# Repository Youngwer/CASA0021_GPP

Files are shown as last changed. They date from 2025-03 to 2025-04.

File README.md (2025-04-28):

LitMate Title

<a href="https://www.youtube.com/watch?v=BeWCd5zH7cs">
  LitMate Demo Video
</a>

🎥 Click the video above to watch [Your New Reading Partner](https://www.youtube.com/watch?v=BeWCd5zH7cs)

# LitMate: Smart Book Light for Shared Reading Experiences

## 📖 What the Project Does

LitMate is a smart book light that combines IoT technology with behavioral development concepts to help users build consistent reading habits. Using the MQTT protocol, LitMate enables remote users to share their reading status in real-time, fostering mutual companionship and accountability.

Product demo of LitMate

**Key Features:**
- Physical book light with open/close mechanism showing reading status
- Visual Pomodoro timer through page angle movement
- LED indicators showing reading progress for yourself and your reading partner
- Touch sensor for interaction and color changes
- Companion mobile app for tracking reading statistics and connecting with other readers
- WiFi connectivity with easy setup through Access Point mode
- MQTT protocol for real-time status synchronization between paired devices

<br clear="left"/>

## 🌟 Why the Project is Useful

LitMate addresses the challenge many readers face: difficulty in maintaining consistent reading habits. According to a 2019 Harris Poll, 81% of U.S. adults report not reading as much as they wish due to limited time. Research on the "false hope syndrome" explains this pattern of repeated failure and renewed intention (Polivy & Herman, 2002).

LitMate transforms reading from a solitary activity into a shared experience by:
1. **Creating accountability** through paired devices that show when your partner is reading
2. **Visualizing progress** with physical and light indicators
3. **Building routine** through Pomodoro timing techniques
4. **Fostering community** via the companion app's social features
5. **Reducing distractions** by making reading time visible and meaningful

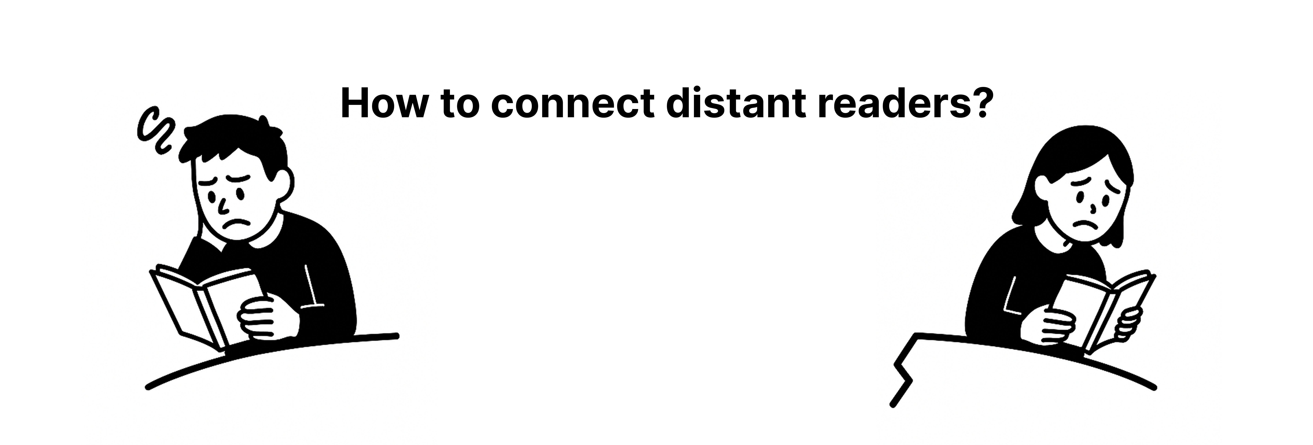
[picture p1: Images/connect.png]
How to connect distant readers

<p style="text-align: center;"><em>How LitMate connects distant readers</em></p>

## 🚀 How Users Can Get Started with the Project

### Materials Required

| Component | Quantity | Estimated Cost (GBP) | Notes |
|---|---|---|---|
| ESP32 Development Board | 1 | £7.2 | Main controller |
| SW420 Vibration Sensor | 1 | £0.8 | For touch detection |
| Servo Motor | 2 | £4.4 | Controls book opening/closing |
| WS2812B LED Strip | 4 segments (8 LEDs each) | £11.0 | For status display |
| Push Button | 1 | £0.4 | Stainless steel button |
| 4xAA Battery Holder | 1 | £0.8 | 6V power supply |
| Acrylic Sheets | - | £8.3 | Textured acrylic recommended |
| Other Components | - | £2.8 | Wires, resistors, etc. |

### Step 1: Hardware Assembly

1. **3D Modeling & Fabrication:**
   - Use the provided [Rhino files](./3D_Models/) for the enclosure design
   - Laser cut the components from acrylic sheets using the [DWG files](./Laser_Cutting/)
   - Follow the [assembly guide](./Documentation/assembly_guide.md) for detailed instructions

2. **Paper Folding:**
   - Use the [origami template](./Documentation/origami_template.pdf) to create the book page structure
   - Attach pages to the servo motors following the diagram in the assembly guide

3. **Circuit Connection:**
   - Wire the components according to the [circuit diagram](./PCB%20Design/Circuit%20diagram.png)
   - For a more permanent solution, the [PCB design](./PCB%20Design/PCB.png) can be manufactured

### Step 2: Software Setup

1. **Prerequisites:**
   - Install [Arduino IDE](https://www.arduino.cc/en/software)
   - Install ESP32 board package via Boards Manager
   - Install required libraries:
     - WiFiManager
     - PubSubClient (MQTT)
     - FastLED
     - ESP32Servo

2. **Loading the Code:**
   - Clone this repository: `git clone https://github.com/yourusername/litmate.git`
   - Open the [Arduino project](./Arduino/) in Arduino IDE
   - Update the `arduino_secrets.h` file with your WiFi and MQTT broker details
   - Upload the code to your ESP32

3. **First Boot & WiFi Setup:**
   - Power on the device
   - Connect to the "ESP32-Config" WiFi network from your phone/computer
   - Navigate to http://192.168.4.1 in a browser
   - Enter your home WiFi credentials
   - The device will restart and connect to your network

### Step 3: Mobile App Setup

1. **Installing the App:**
   - Download the APK from the [Releases](https://github.com/yourusername/litmate/releases) page
   - Install on your Android device (currently Android-only)

2. **Setting Up Your Profile:**
   - Create an account
   - Set reading goals
   - Add books to your library
   - Connect with friends or join reading groups

### Step 4: Pairing Devices

1. Configure both LitMate devices to use the same MQTT broker
2. Assign each device a unique ID in the code (DeviceA and DeviceB)
3. Both devices will automatically synchronize when connected to the network

## 🤝 Where Users Can Get Help

- **Documentation:** Complete documentation is available in the [Documentation](./Documentation/) folder
- **Issues:** Submit problems or feature requests through [GitHub Issues](https://github.com/yourusername/litmate/issues)
- **Discussions:** Join our [Discord community](https://discord.gg/litmate) to connect with other makers
- **Contact:** Reach the development team at litmate@example.com

## 👥 Who Maintains and Contributes to the Project

LitMate was developed by the CEuniverse Team as part of the CASA0016 Making & Prototyping course at UCL:

<div style="text-align: center;">
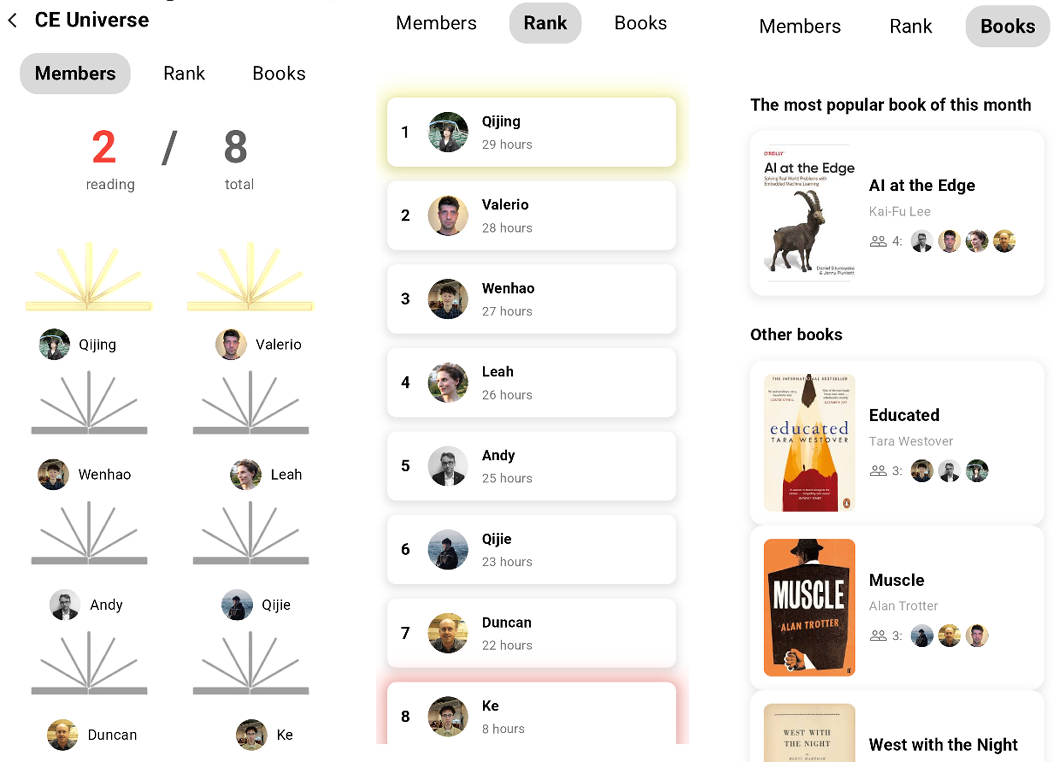
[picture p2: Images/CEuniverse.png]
CEuniverse Team
    
</div>

Team members:
- [Member 1] - Hardware Design & Fabrication
- [Member 2] - Software Development
- [Member 3] - Mobile App Development
- [Member 4] - Product Design
- [Member 5] - Documentation & Testing

## 🔧 Technical Details

### System Architecture

<div style="text-align: center;">
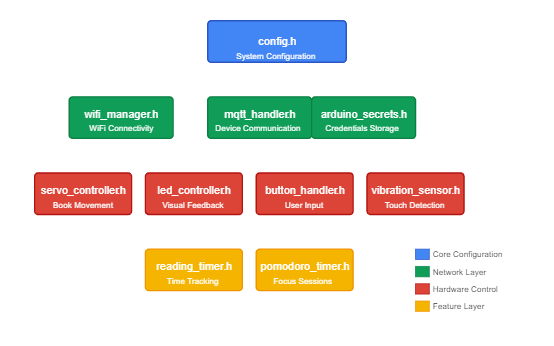
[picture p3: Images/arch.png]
System Architecture
    
</div>

When significant state changes occur (book opening/closing, touch interaction, light color change), the device immediately publishes updates to the appropriate topics. The MQTT client maintains persistent connections with automatic reconnection mechanisms to ensure connected devices receive the latest state information.

Therefore, this lightweight communication framework enables the paired LitMate devices to maintain synchronized state and respond to each other's actions in real-time within seconds.

### 4.3 Core Reading Functionality
The core of LitMate's functionality revolves around its ability to physically interact with books, track reading sessions, and provide visual feedback through an integrated system of hardware control and state management.

#### 4.3.1 Pomodoro Timer 
The LitMate device incorporates a sophisticated Pomodoro timer that combines time tracking with physical visualization through servo motor positioning.

The Pomodoro functions are tightly integrated with the book state management system: When book is open, it start working, set an hour Pomodoro timer; When the full one-hour session completes, it triggers the book closure mechanism.

##### Servo Angle as Visual Progress Indicator
Another feature of LitMate's Pomodoro is the use of servo angle position as a physical progress indicator. As reading time advances, the servo motors adjust their position in 15-degree increments:

```cpp
if (currentStage != lastServoStage) {
        // Calculate new servo position: starting from 180 degrees, decreasing by 15 degrees per stage
        int targetPosition = 180 - (currentStage * DEGREES_PER_STAGE);
        
        // Smoothly move to the new position
        moveServosSmooth(180 - (lastServoStage * DEGREES_PER_STAGE), 
                          targetPosition, 
                          (lastServoStage < currentStage) ? 5 : -5, 
                          50);
        
        lastServoStage = currentStage;
    }

```

#### 4.3.2 Button Interaction Logic (Short Press vs. Long Press)
The system uses a single button interface with differentiated press durations to control multiple functions. The button handler utilise debouncing and timing mechanisms to distinguish between short and long presses:
- **Short Press**: Toggles the progress indicator LEDs on/off.
- **Long Press (for more than 3 seconds)**: Toggles the book's open/closed state.

```cpp
// Function to check button status
void checkButton() {
    // Read button state (LOW means pressed)
    int buttonState = digitalRead(BUTTON_PIN);
    
    // Button pressed
    if (buttonState == LOW && !buttonPressed) {
        buttonPressed = true;
        buttonPressTime = millis();
        longPressTriggered = false;
    } 
    
    // Button held down, check if long press duration is reached
    else if (buttonState == LOW && buttonPressed) {
        unsigned long pressDuration = millis() - buttonPressTime;
        
        // Long press duration reached and long press action not yet triggered
        if (pressDuration >= LONG_PRESS_TIME && !longPressTriggered) {
            toggleBook();         // Toggle the book's open/close status
            longPressTriggered = true;
            Serial.println("Long press detected, toggling book status");
        }
    }
    // Button released
    else if (buttonState == HIGH && buttonPressed) {
        unsigned long pressDuration = millis() - buttonPressTime;
        buttonPressed = false;
        
        // Short press - control LED lights
        if (pressDuration < LONG_PRESS_TIME && !longPressTriggered) {
            toggleLEDs();
            Serial.println("Short press detected, toggling LED status");
        }
        longPressTriggered = false;
    }
}
```

#### 4.3.3 Session-based and Cumulative Time Tracking
The system can distinguish between active reading sessions and cumulative daily reading time. When the book is opened, a new reading session begins. The system uses the millis() function to track time and records the start time and begins tracking the session duration. When the book is closed, the session duration is calculated and added to the cumulative daily reading time. This approach allows the system to maintain accurate time records even through multiple reading sessions throughout the day. The related code is shown below:
```cpp
// Start reading timer
void startReadingTimer() {
    startTime = millis();
    lastUpdateTime = startTime;
    Serial.println("Reading session started!");
    
    // Publish reading status to MQTT
    publishReadingStatus(true, dailyReadingTime);
}
// Stop reading timer
void stopReadingTimer() {
    if (startTime > 0) {
        unsigned long sessionTime = millis() - startTime;
        dailyReadingTime += sessionTime;
        Serial.print("Reading session ended. Session time: ");
        printTime(sessionTime);
        Serial.print("Total daily reading time: ");
        printTime(dailyReadingTime);
        
        // Publish reading status to MQTT
        publishReadingStatus(false, dailyReadingTime);
        
        startTime = 0;
    }
}
```

#### 4.3.4 Daily Reading Reset Mechanism
When a new day begins, the system logs the previous day's total reading time, resets the counter, and publishes the updated state to the MQTT network to ensure paired devices are synchronized.

### 4.4 User Interaction and Data Visualisation

#### 4.4.1 LED Indication System

##### Book Lamp
The main book lamp serves as both a reading light and a status indicator, using color and animation effects to visualise the device's state.

When both books are open, the Book Lamp will display a smooth "breathing" effect that provides ambient lighting, which enhances the reading experience across both users, creating a reading atmosphere.

```cpp
void updateBreathingEffect() {
    unsigned long currentTime = millis();
    if (currentTime - lastBreathTime >= BREATH_INTERVAL) {
        if (increasing) {
            brightness += 5;
            if (brightness >= 255) {
                brightness = 255;
                increasing = false;
            }
        } else {
            brightness -= 5;
            if (brightness <= 0) {
                brightness = 0;
                increasing = true;
            }
        }
	lastBreathTime = currentTime;
}
```
The book lamp color can be changed between pink (default) and yellow through the vibration sensor double-tap detection, which is design for interactive purposes to increase fun through readers:
```cpp
if (tapInterval > minTapInterval && tapInterval < doubleTapWindow) {
    // Toggle light color and publish
    isYellowColor = !isYellowColor;
    publishLightColor(isYellowColor);
    
    // Apply the new color to LEDs
    if (isYellowColor) {
        setLEDColor(255, 255, 0);  // Yellow
    } else {
        setLEDColor(255, 102, 178);  // Pink
    }
}

```
This color change is synchronized between paired devices, creating a shared visual experience between remote users.

#### 4.4.2 Progress Indicator LEDs

The system implements separate LED strips for each user, which can be identified by color, to visualise reading time for both the user's device and the paired device. The number of LED display logic is shown in code below:
```cpp
// Map reading time to LED display (8 LEDs represent progress thresholds)
    int ledsToLight = 0;
    if (totalSeconds < 450) {
        ledsToLight = 1;
    } else if (totalSeconds < 900) {
        ledsToLight = 2;
    } else if (totalSeconds < 1350) {
        ledsToLight = 3;
    } else if (totalSeconds < 1800) {
        ledsToLight = 4;
    } else if (totalSeconds < 2250) {
        ledsToLight = 5;
    } else if (totalSeconds < 2700) {
        ledsToLight = 6;
    } else if (totalSeconds < 3150) {
        ledsToLight = 7;
    } else {
        ledsToLight = 8;
    }
```

Also, these reading progress LEDs can be switched on and off via a short button press to conserve power, which is shown below:
```cpp
    if (!progressLEDsEnabled) {
        // Turn off both progress bar LEDs
        timeStrip.clear();
        timeStrip.show();
        
        deviceBTimeStrip.clear();
        deviceBTimeStrip.show();
    } else {
        // Re-enable progress bar LEDs
        updateTimeLEDs();
        updateDeviceBTimeLEDs();
    }
```

# 5. Application

### 5.1 Overview
The mobile application aims to provide users with a simple reading record and reading sharing experience. It ensures that users can record the current reading time and number of pages, and view past reading statistics through the app to achieve better development of reading habits.

### 5.2 Main Functions
#### 5.2.1 Recording reading time and pages

<div style="text-align: center;">
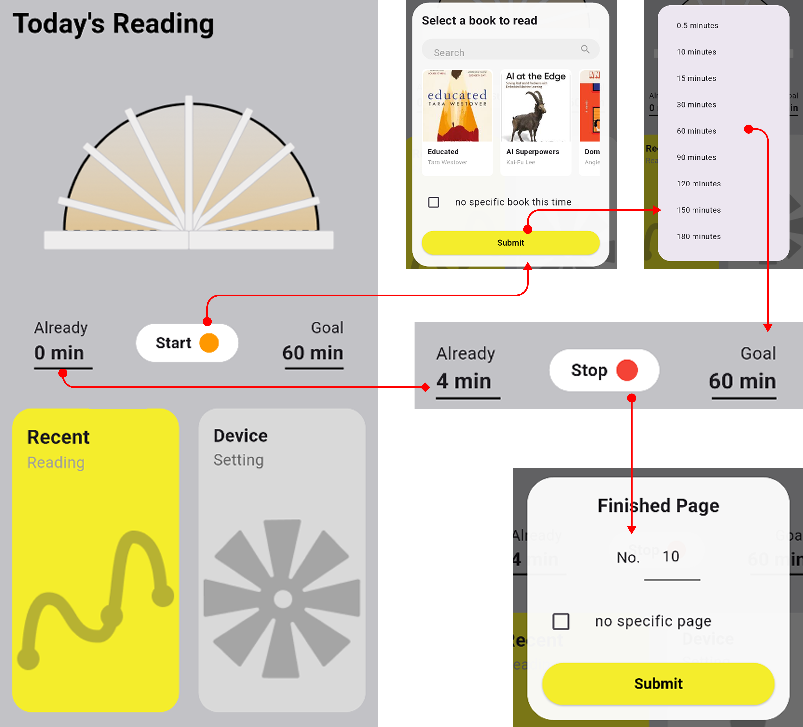
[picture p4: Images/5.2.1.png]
Recording reading time and pages interface
    
    <p><em>Fig 24. Interface for recording reading time and pages</em></p>
</div>

- Click on the 'Goal' button and select the goal for today's reading time in the pop-up window.
- Click on the 'Start' button to select the book you are going to read in the pop-up window (the data of the book in the pop-up window comes from the Library).
- After starting to read, the 'Already' text will show the length of time already read, users can click the 'Stop' button to stop reading records, you can enter the progress of this reading in the pop-up window that appears after clicking.

#### 5.2.2 Viewing Reading Statistics

<div style="text-align: center;">
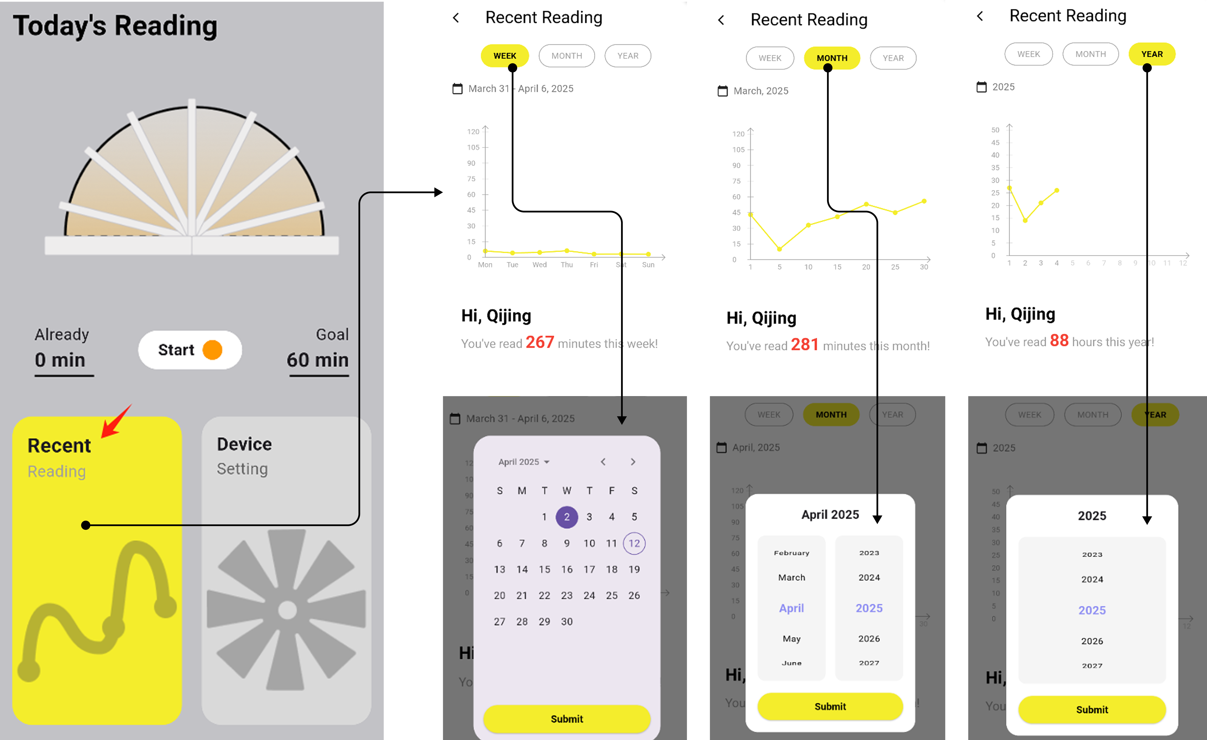
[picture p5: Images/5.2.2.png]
Reading statistics overview
    
    <p><em>Fig 25. Reading statistics overview showing weekly, monthly, and yearly views with time selection</em></p>
</div>

- Click on 'Recent Reading' on the homepage to go to the statistics page. 
- Click on 'WEEK', 'MONTH', 'YEAR' to see reading statistics in different time units.
- Click on the calendar icon to select a time in the pop-up window

#### 5.2.3 Managing Personal Library

<div style="text-align: center;">
    Personal library interface
    <p><em>Fig 26. Personal library interface showing book collection with progress bars</em></p>
</div>

- The book cards on the Library page show each book's cover, title, author, and current reading progress bar.
- Click on the 'Add a new book' card to add a book to the e-library and enter information about the new book in the pop-up window.
- In the search box, you can enter the name of the book or author to search for existing book data.

#### 5.2.4 Managing Personal Library
Click the plus sign on the Group page to create a new group, and enter the group information in the pop-up window.
<div style="text-align: center;">
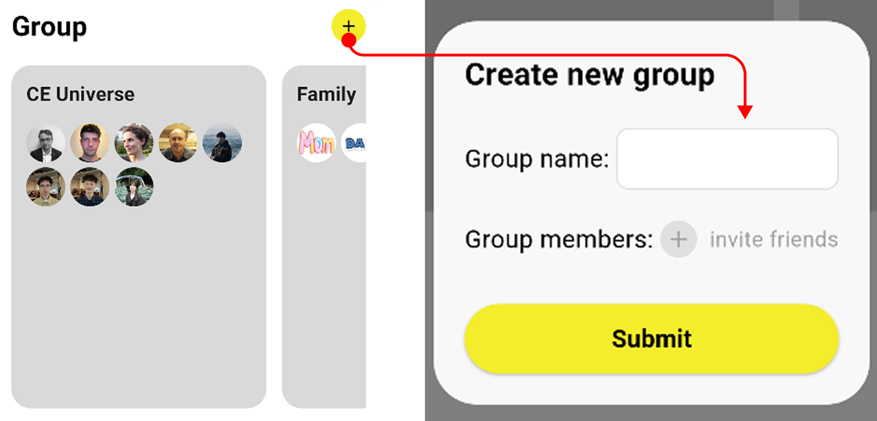
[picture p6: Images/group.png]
Group Photo
    
    <p><em>Fig 27. Group Photo</em></p>
</div>

Click on each Group card to see more information about the group, including the number of members currently reading, the ranking of reading hours for the month, and the books read by group members.
<div style="text-align: center;">
    CEuniverse
    <p><em>Fig 28. CEuniverse Team</em></p>
</div>

### 5.3 Interation
#### 5.3.1 Sketch

<div style="text-align: center;">
    App interface sketch
    <p><em>Fig 29. Initial sketches of the app interface design</em></p>
</div>

#### 5.3.2 Prototype

<div style="text-align: center;">
    App interface prototype
    <p><em>Fig 30. High-fidelity prototype of the app interface</em></p>
</div>

#### 5.3.3 Current Development

<div style="text-align: center;">
    Current app development
    <p><em>Fig 31. Current development status of the app interface</em></p>
</div>

# **6. Limitations & Future development**
### 6.1 More Possibilities in Design

<div style="text-align: center;">
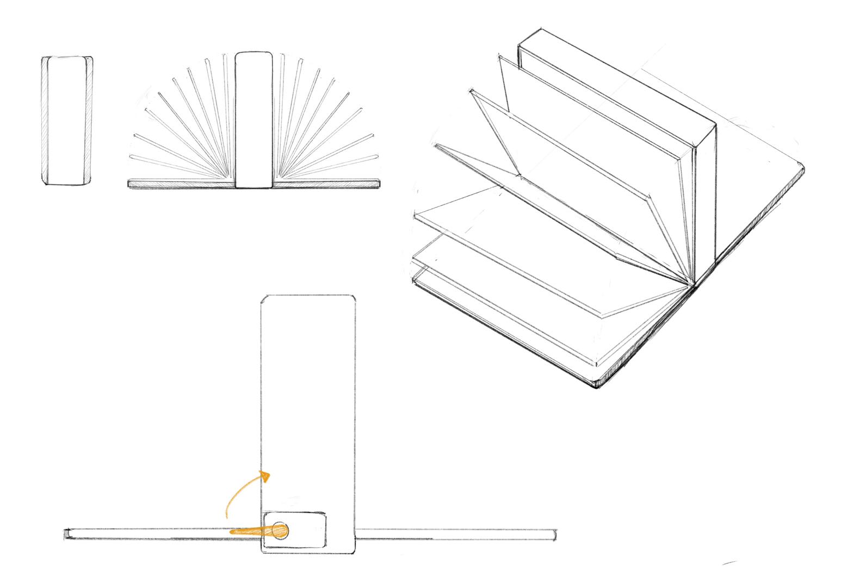
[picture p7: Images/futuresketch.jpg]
Future Design Possibilities
    
    <p><em>Fig 32. Future Design Possibilities</em></p>
</div>
Some of the advice about the product gained during the pitch made the team rethink about product design.

- **Size**: The team tends to reduce the size of the product in the next iteration by upgrading the hardware to make it more write and easy to use. In fact, the current product still has a lot of free space inside.
- **Visualisation**: For visualisation, the team preferred to make another prototype where the pages of the book could be opened from each side to represent the reading progress of both sides for a more intuitive comparison.

### 6.2 How to Improve Hardware of LitMate?
#### 6.2.1 Circuit Assembly and Challenges
The circuit was designed to be straightforward, focusing on ease of connection. However, the symmetrical layout made wiring more complex, leading to issues in organization and debugging. The key challenges faced during assembly were:
- **Complex Wiring Layout**: The symmetrical arrangement of components made routing difficult, increasing the risk of loose connections.
- **Power Supply Limitations**: The initial single power source was insufficient for stable operation, especially when driving multiple LEDs and servos.
- **Vibration Sensor Sensitivity**: The SW420 sensor was difficult to fine-tune, sometimes failing to detect subtle touches or triggering false readings.

To address these issues, some measures were taken :
1) Simplified the routing layout, reducing unnecessary wiring complexity.
2) Implemented a separate power supply, ensuring adequate power distribution.
3) Adjusted the sensitivity threshold of the SW420 sensor to improve its reliability.

#### 6.2.2 PCB Design
For the purpose of simplifying the hardware assembly of the product as well as reducing the size of the product. Designing a dedicated PCB is an ideal ending solution and the team has made the following attempts so far:

<div style="text-align: center;">
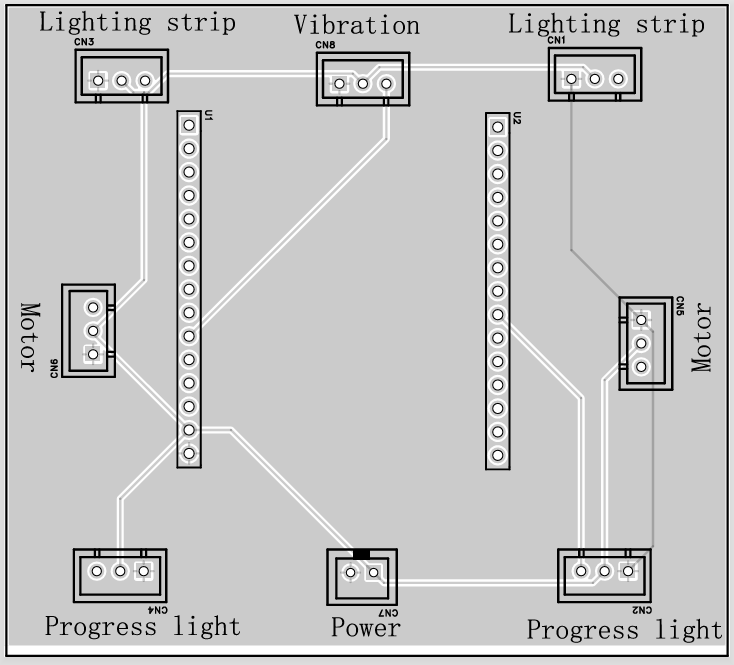
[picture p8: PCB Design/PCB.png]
PCB Design
    
    <p><em>Fig 33. PCB Design</em></p>
</div>

### 6.3 Application

The current APP is limited to Android mobile phones and has not yet been linked to a physical book light, which could be developed in both directions in future developments and iterations: 
1) Develop different versions of the app for Android and IOS phones; 
2) Implement a digital twin between mobile application and physical book light, allowing users to control the book light on/off and synchronise the reading time recorded by the book light in the application.

### 6.4 Marketisation：Inability to finally recognise costs
Below are the current individual equipment costing：

| Component | Quantity | Subtotal (GBP) | Estimated Cost (GBP) | Notes |
|---|---|---|---|---|
| ESP32 Development Board | 1 | £5.5-£8.8 | £7.2 | Main controller |
| SW420 Vibration Sensor | 1 | £0.55-£1.1 | £0.8 | For touch detection |
| Servo Motor | 2 | £3.3-£5.5 | £4.4 | Controls book opening/closing |
| WS2812B LED Strip | 4 segments (8 LEDs each) | £8.8-£13.2 | £11.0 | For status display |
| Push Button | 1 | £0.22-£0.55 | £0.4 | Stainless steel button |
| 4xAA Battery Holder | 1 | £0.55-£1.1 | £0.8 | 6V power supply |
| Acrylic Enclosure | - | £5.5-£11 | £8.3 | Including laser cutting cost |
| Other Components (Wires, Resistors, etc.) | - | £2.2-£3.3 | £2.8 | Basic electronic components |
| **Total** | - | **£26.6-£44.5** | **£35.7** | - |

The ultimate goal of the product is to sell it on kickstater, so the cost and selling price need to be considered, but there are two uncertainties at the moment: the **paper-folding work** needs to seek cooperation from manufacturers for mass production, and the **subsequent development and maintenance costs of the APP**.

# **7. Reference**
1) Polivy, J., & Herman, C. P. (2002). If at First You Don't Succeed: False Hopes of Self-Change. American Psychologist, 57(9), 677–689. https://doi.org/10.1037/0003-066X.57.9.677
2) Harris Poll (2019). Reading Habits Survey, conducted for Scribd. Summary available via Mental Floss by Garin Pirnia: 81% of people don't read as much as they want
3) Wing, R. R., & Jeffery, R. W. (1999). Benefits of recruiting participants with friends and increasing social support for weight loss and maintenance. Journal of Consulting and Clinical Psychology, 67(1), 132–138. https://doi.org/10.1037/0022-006X.67.1.132

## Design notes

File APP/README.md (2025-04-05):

# **workshop7app**

A new Flutter project.

## **Getting Started**

This project is a starting point for a Flutter application.

A few resources to get you started if this is your first Flutter project:

- [Lab: Write your first Flutter app](https://docs.flutter.dev/get-started/codelab)
- [Cookbook: Useful Flutter samples](https://docs.flutter.dev/cookbook)

For help getting started with Flutter development, view the
[online documentation](https://docs.flutter.dev/), which offers tutorials,
samples, guidance on mobile development, and a full API reference.

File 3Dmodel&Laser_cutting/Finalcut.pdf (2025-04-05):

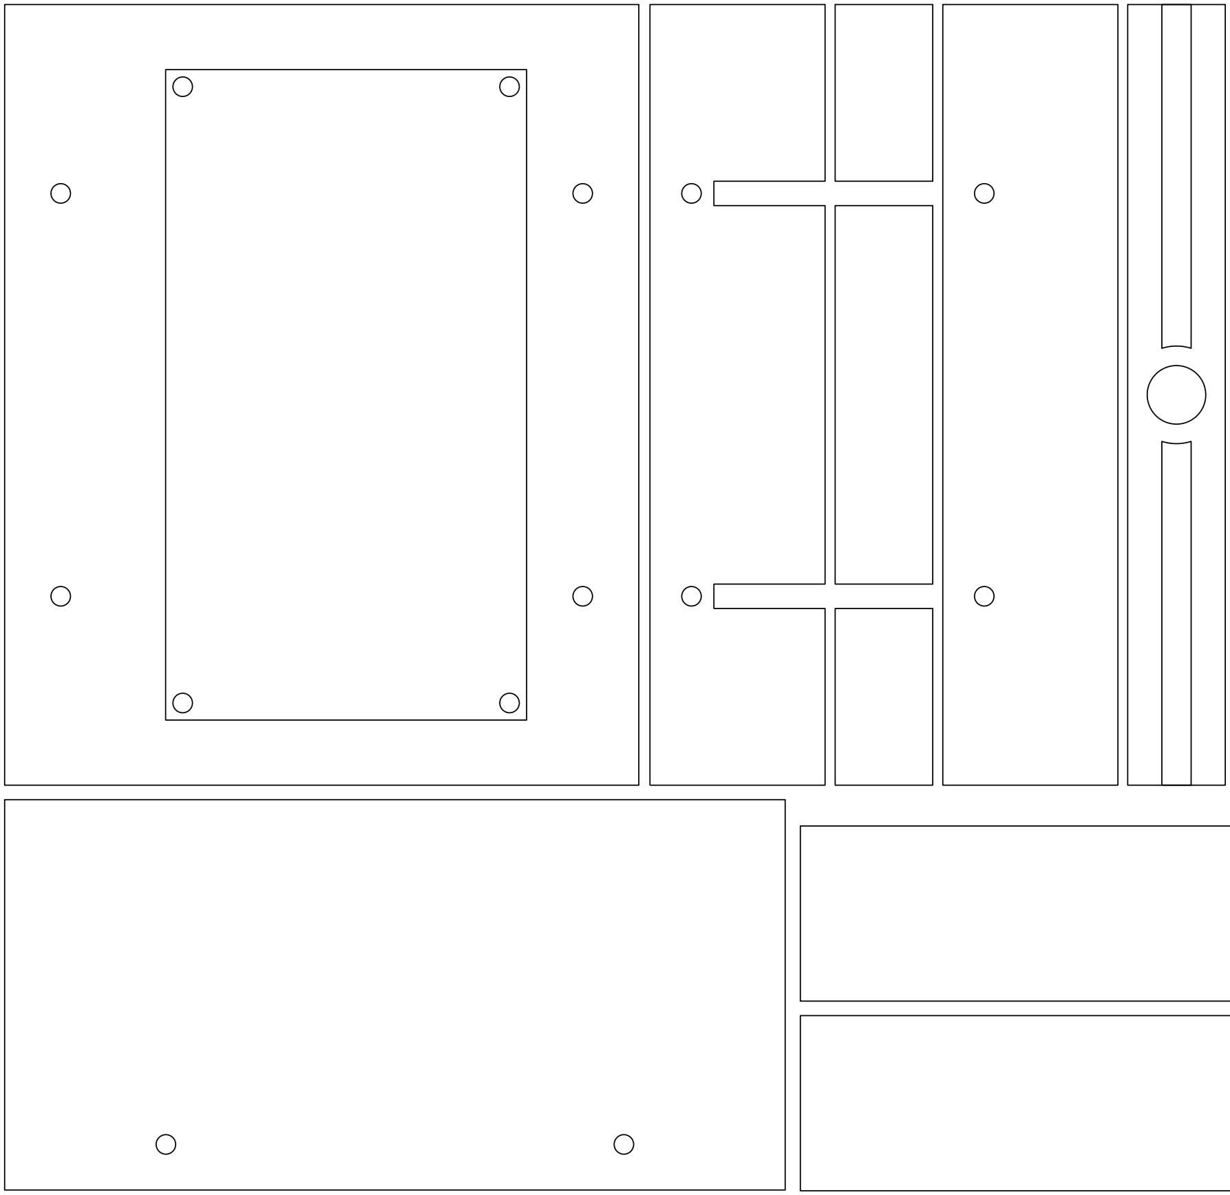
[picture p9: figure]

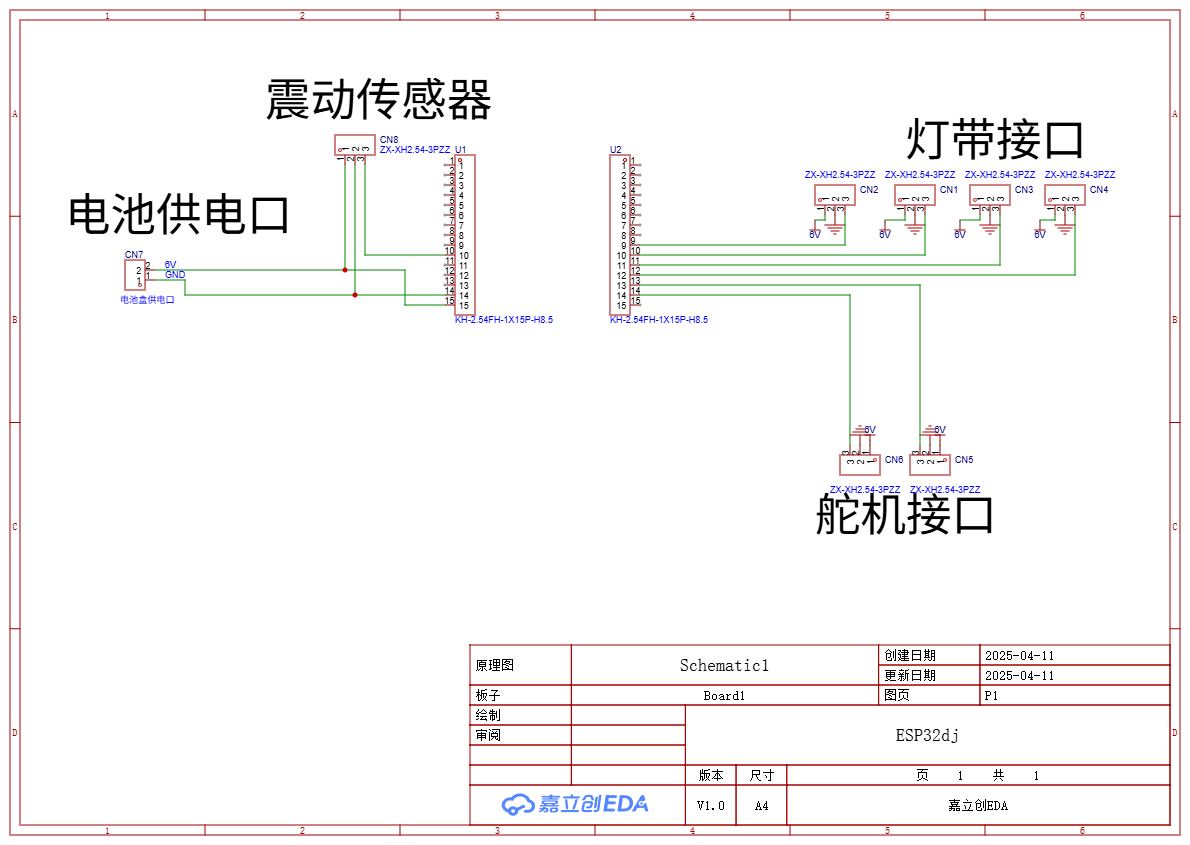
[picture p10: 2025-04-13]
PCB Design/b82df3840280ed77bfbe4476844dcdd.png

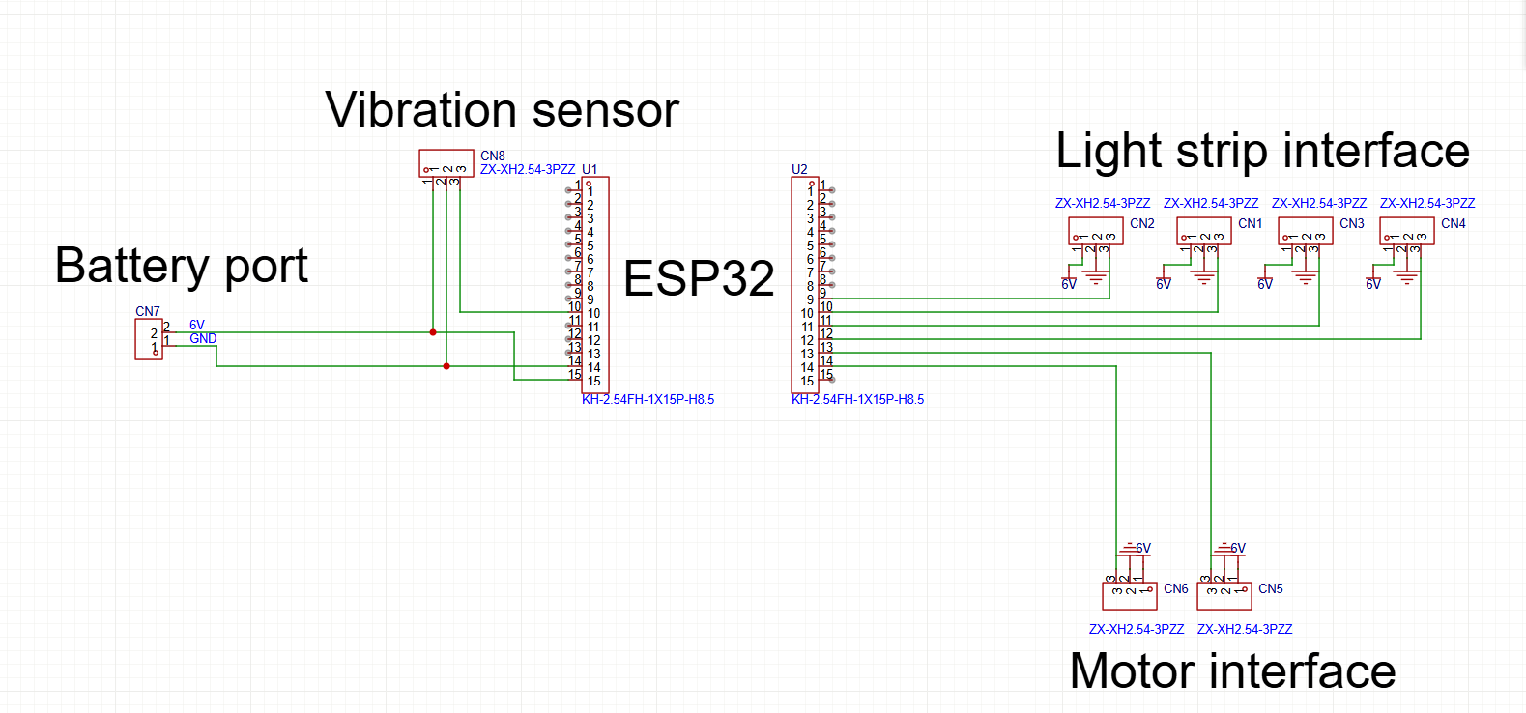
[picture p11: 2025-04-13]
PCB Design/Circuit diagram.png

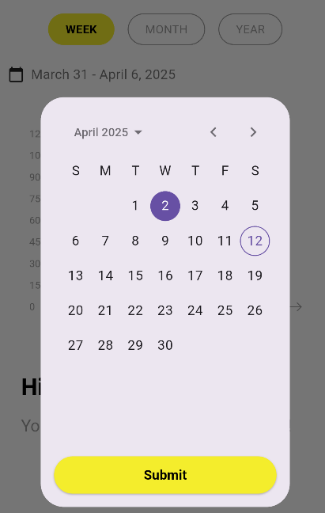
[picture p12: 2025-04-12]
Images/app_day.png

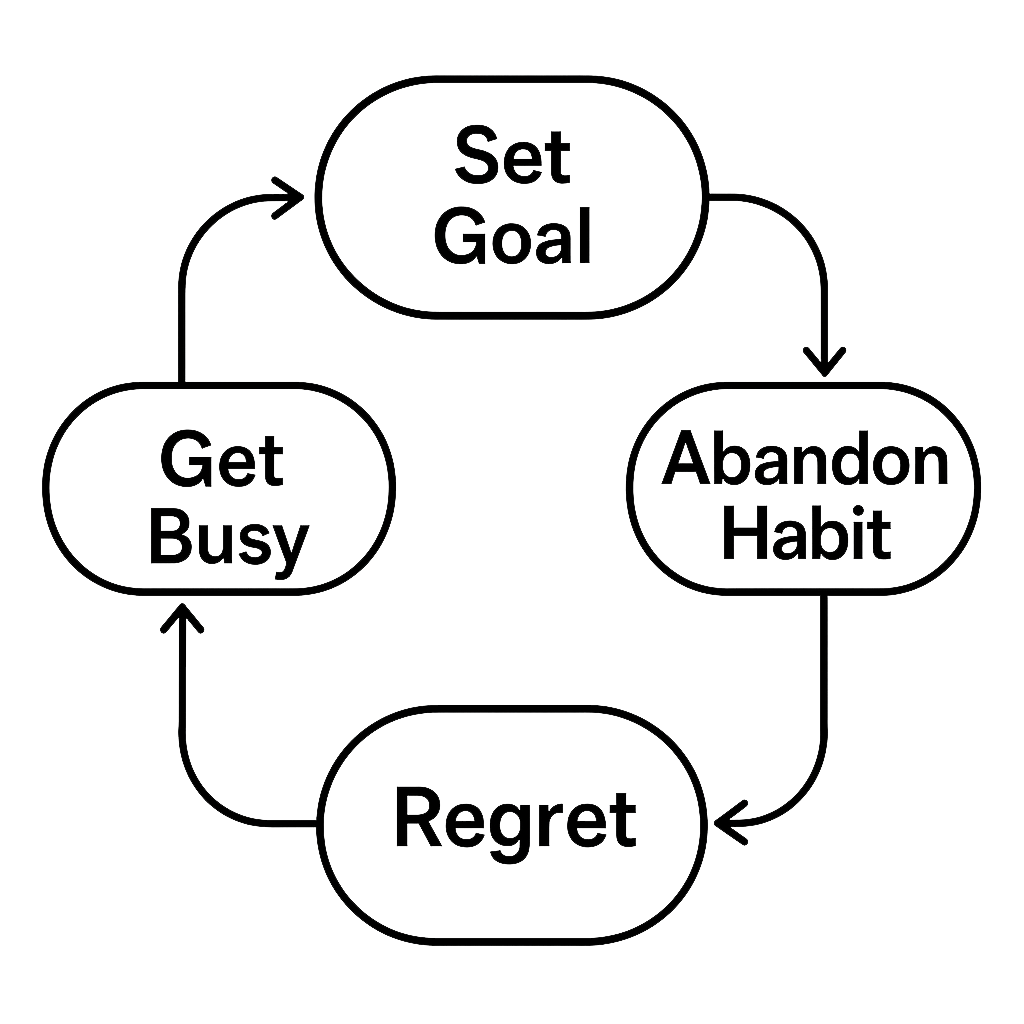
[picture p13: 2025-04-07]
Images/Circle.png

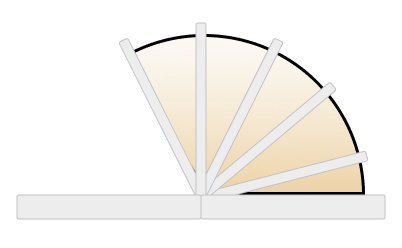
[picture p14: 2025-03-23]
APP/assets/images/Animation/R4.png

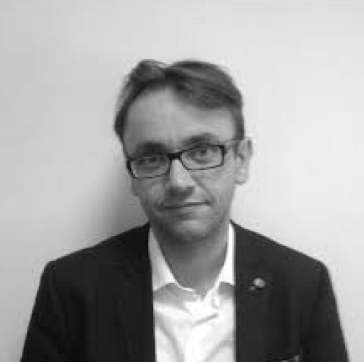
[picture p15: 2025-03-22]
APP/assets/images/Andy.png

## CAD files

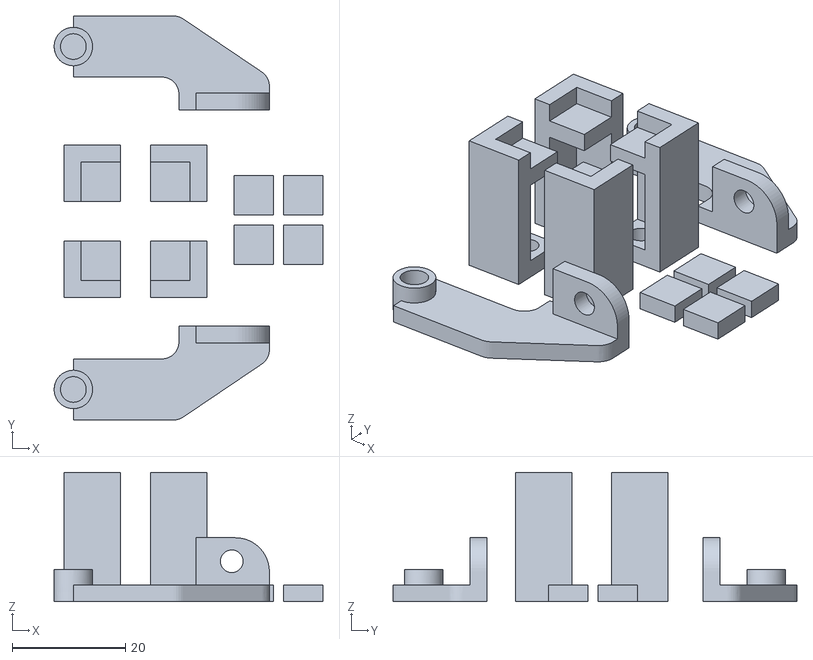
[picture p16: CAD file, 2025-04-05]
3Dmodel&Laser_cutting/finalholder.stl
47.5 x 71.4 x 22.9

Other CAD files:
3Dmodel&Laser_cutting/Enclosure_split.3dm

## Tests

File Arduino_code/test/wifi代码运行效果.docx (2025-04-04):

1. 连接ESP323、运行代码
2. 用手机或电脑打开wifi页面，连接ESP32生成的热点

账号：ESP32-Config

密码：12345678

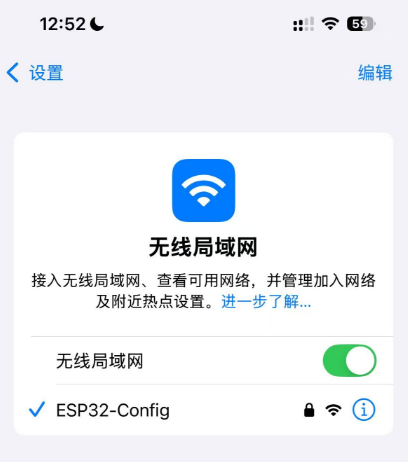
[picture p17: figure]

3. 连接之后用该设备打开网页http://192.168.4.1，如图所示，输入希望设备配置的wifi名称和密码，提交后如右图所示

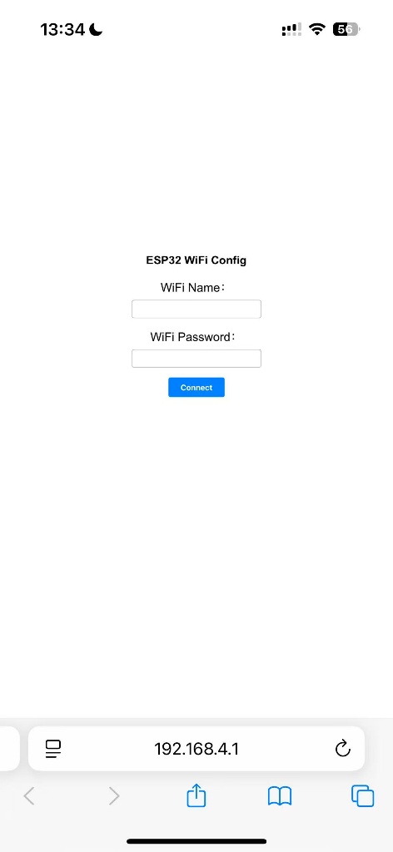
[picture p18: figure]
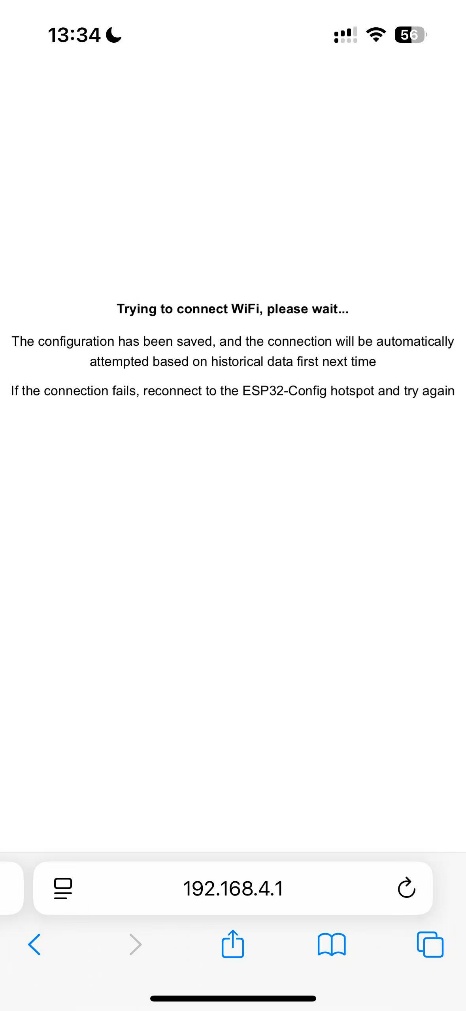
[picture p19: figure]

4. 整个过程，串口打印信息如图所示：

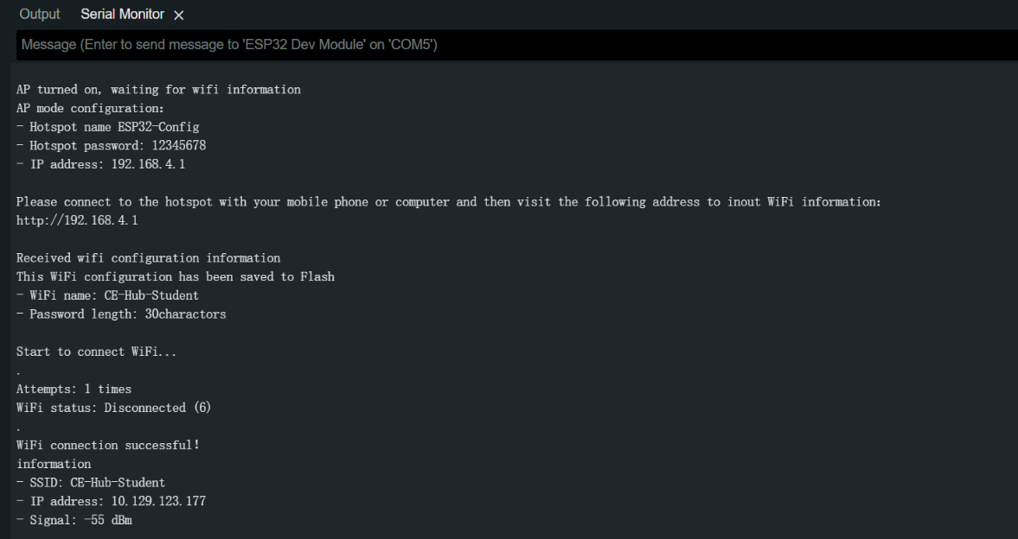
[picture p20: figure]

5. 成功连接后ESP32会自动记录该wifi信息，每次重启板子、它都会先在历史记录里搜索是否有可连接的wifi信息，如果有的话就自动连接了，没有的话就打开AP模式开启热点等待用户连接和输入信息。比如教室的wifi已录入，之后不需要再输入账号密码连接了

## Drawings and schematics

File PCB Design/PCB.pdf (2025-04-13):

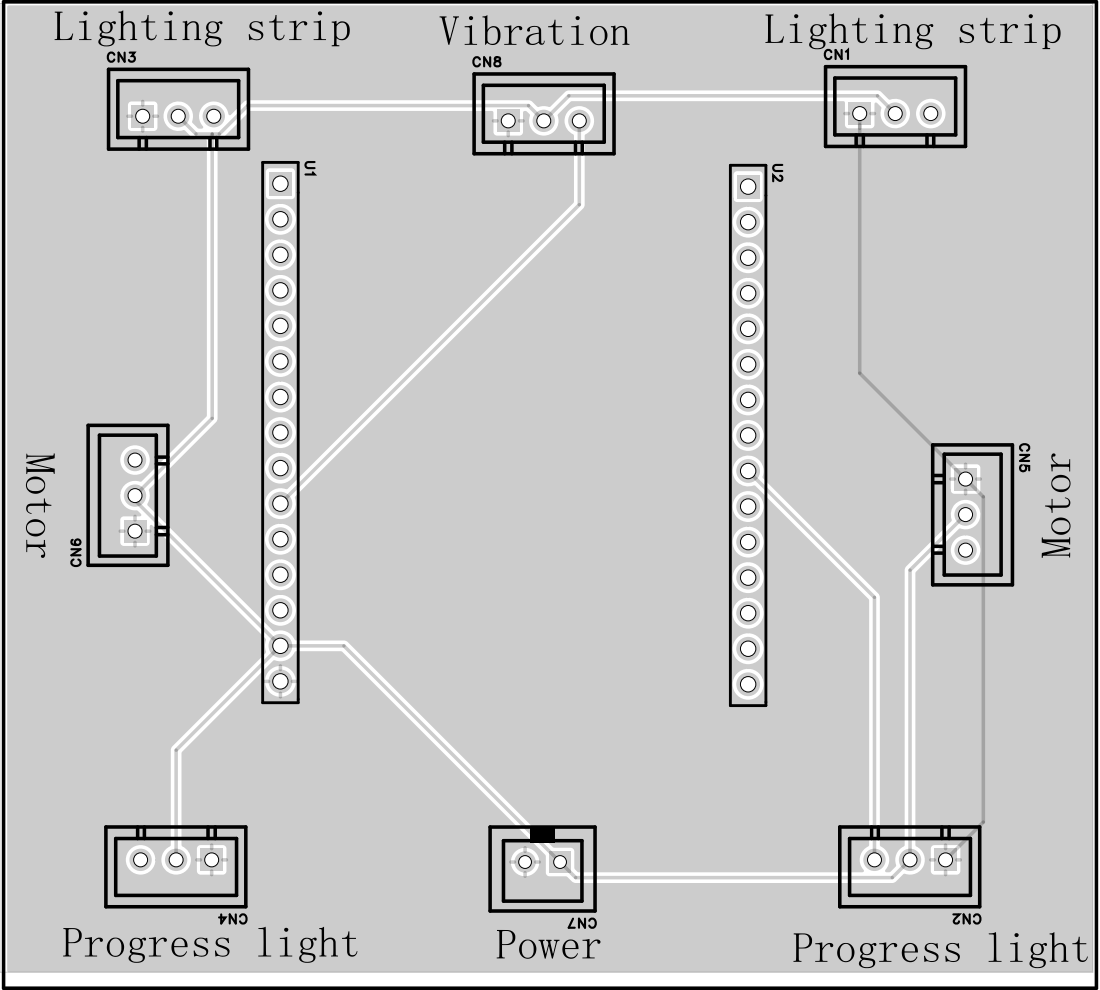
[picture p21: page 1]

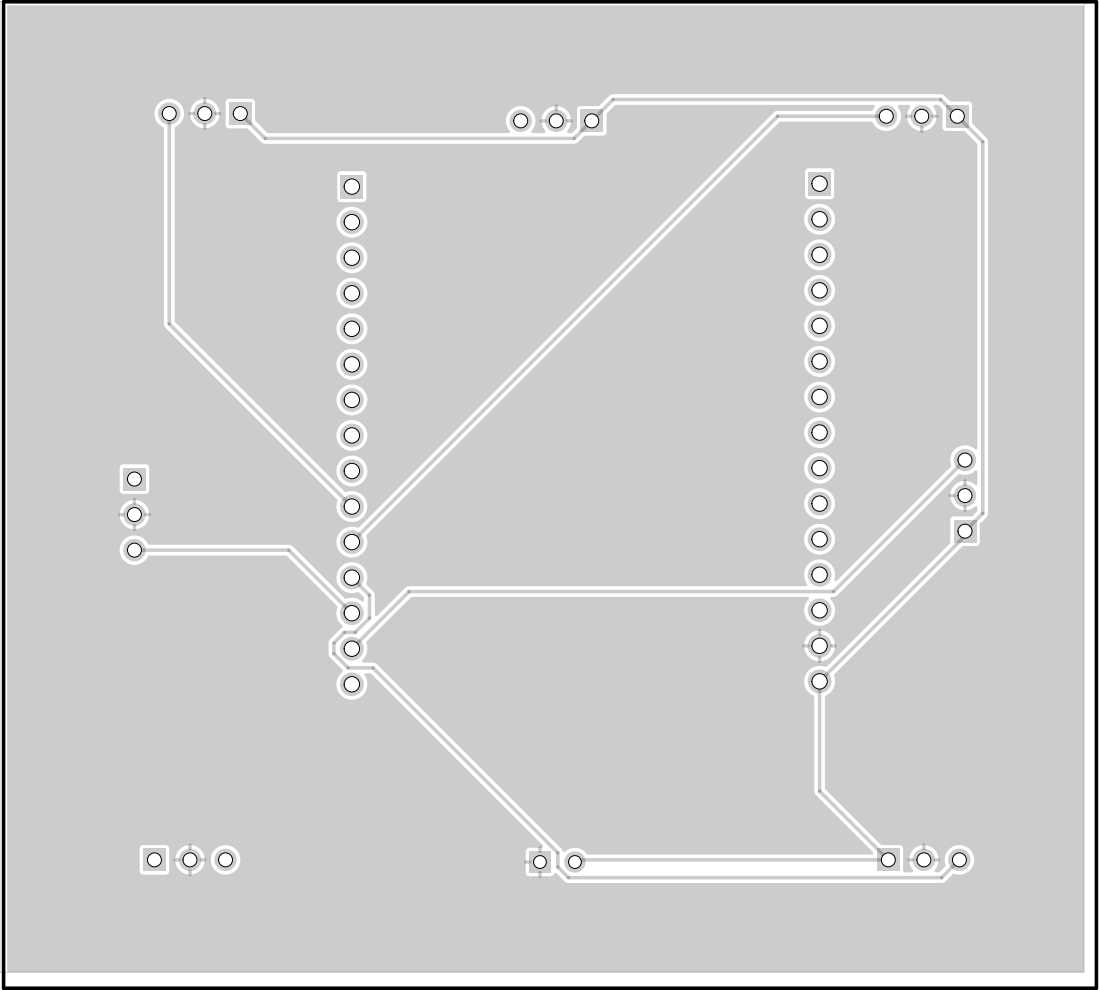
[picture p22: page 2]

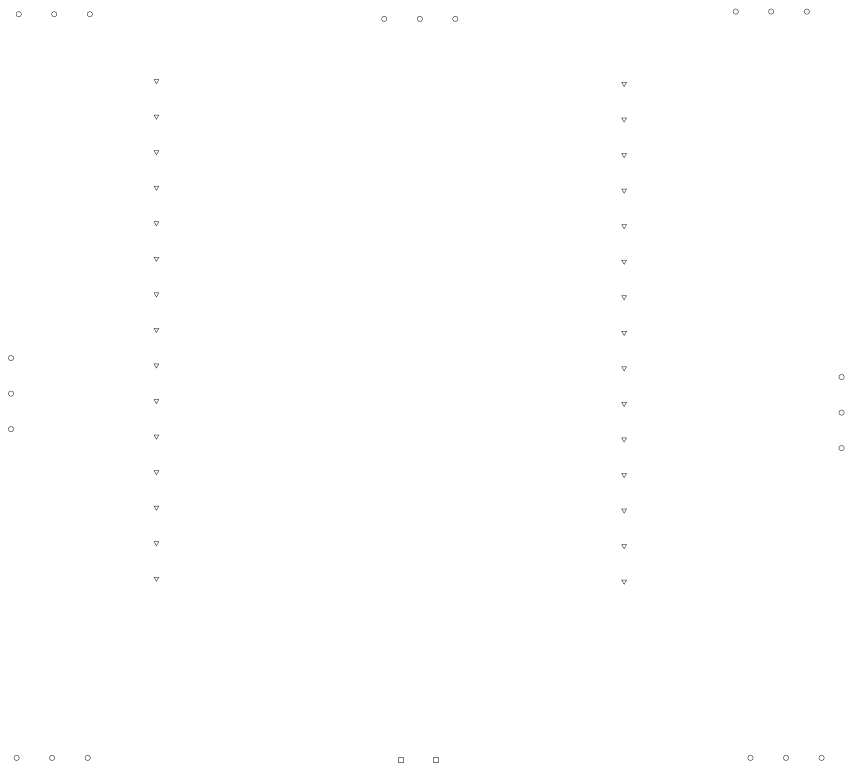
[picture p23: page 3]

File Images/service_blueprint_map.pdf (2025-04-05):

# Service Blueprint

01 | 02 | 03 | 04 | 05

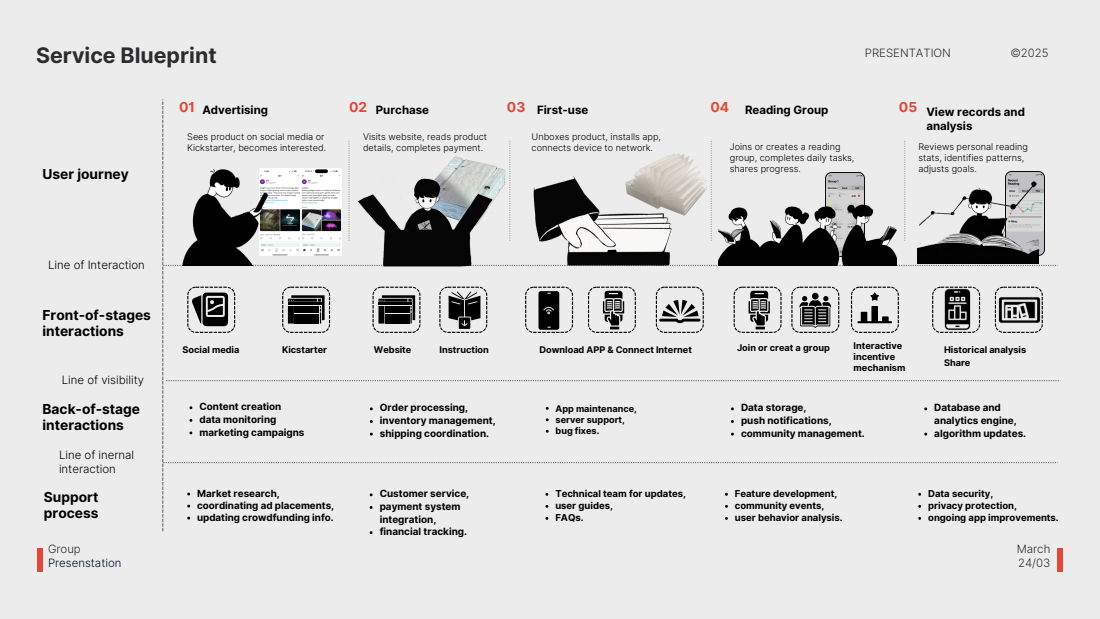
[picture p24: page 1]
PRESENTATION; Group Presenstation; March 24/03; User journey; Advertising; Social media; Kicstarter; Website; Instruction; Join or creat a group; Interactive; incentive mechanism; Historical analysis Share; App maintenance, server support, bug fixes.; Content creation data monitoring marketing campaigns; Customer service, payment system integration, financial tracking.; Order processing, inventory management, shipping coordination.; Data storage, push notifications, community management.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

Sees product on social media or
Kickstarter, becomes interested.

Visits website, reads product
details, completes payment.

Unboxes product, installs app,

Reviews personal reading
stats, identifies patterns,
adjusts goals.

group, completes daily tasks,
shares progress.

Line of Interaction

Front-of-stages
interactions

Created by Book_Collection
from the Noun Project

Download APP & Connect Internet

Line of visibility
Back-of-stage

Line of inernal
interaction
Support
process

Market research,
coordinating ad placements,
updating crowdfunding info.

Technical team for updates,
user guides,
FAQs.

Feature development,
community events,
user behavior analysis.

Data security,
privacy protection,
ongoing app improvements.

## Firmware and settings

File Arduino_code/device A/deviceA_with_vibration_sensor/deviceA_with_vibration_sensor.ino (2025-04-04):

#include "config.h"
#include "mqtt_handler.h"
#include "servo_controller.h"
#include "led_controller.h"
#include "button_handler.h"
#include "reading_timer.h"
#include "pomodoro_timer.h"
#include "wifi_manager.h"
#include "vibration_sensor.h"

// 全局对象实例化
Servo servo1;
Servo servo2;
Adafruit_NeoPixel strip(NUM_LEDS, LED_PIN, NEO_GRB + NEO_KHZ800);
Adafruit_NeoPixel strip2(NUM_LEDS, LED_PIN2, NEO_GRB + NEO_KHZ800);
Adafruit_NeoPixel timeStrip(NUM_TIME_LEDS, TIME_LED_PIN, NEO_GRB + NEO_KHZ800);
Adafruit_NeoPixel deviceBTimeStrip(NUM_DEVICEB_TIME_LEDS, DEVICEB_TIME_LED_PIN, NEO_GRB + NEO_KHZ800);
WiFiClient espClient;
PubSubClient client(espClient);

// 全局状态变量实例化
bool isOpen = false;                         // 书的状态
bool isTouch = false;                        // 当前设备的触摸状态
bool otherDeviceIsTouch = false;             // 另一设备的触摸状态
bool progressLEDsEnabled = true;             // 进度灯状态
unsigned long dailyReadingTime = 0;          // 每日阅读时间
unsigned long startTime = 0;                 // 当前阅读会话开始时间
bool deviceBIsReading = false;               // 设备B的阅读状态
unsigned long deviceBTotalDailyTime = 0;     // 设备B的每日总阅读时间
bool isYellowColor = false;                  // 灯光颜色状态（false=粉色，true=黄色）

void setup() {
    Serial.begin(115200);
    Serial.println("Starting setup...");
    
    // 初始化各个模块
    setupButton();
    setupServos();
    setupLEDs();
    setupReadingTimer();
    setupPomodoro();
    setupVibrationSensor();

    // 设置WiFi连接
    bool wifiReady = setupWiFiManager();
    
    // 只有当WiFi连接成功后才初始化MQTT
    if (wifiReady) {
        setupMQTT();
    }
    
    Serial.println("Setup complete");
}

void loop() {
    // 检查并维护WiFi连接
    checkWiFiConnection();
    
    // 只有在WiFi连接成功的情况下才处理MQTT
    if (wifiConnected) {
        // 确保MQTT连接
        if (!client.connected()) {
            reconnectMQTT();
        }
        client.loop();
        
        // 更新阅读时间到MQTT
        updateReadingTime();
    }
    
    // 本地功能始终运行，不依赖于WiFi连接
    checkDailyReset();
    updateTimeLEDs();
    updateDeviceBTimeLEDs();
    checkButton();
    updatePomodoro();
    checkVibration();  // 振动检测

    // 根据书的状态和灯光颜色状态更新LED效果
    if (isOpen) {
        if (deviceBIsReading) {
            // 当另一设备也在阅读时，使用呼吸灯效果
            updateBreathingEffect();  // 使用修改后的无参数版本，内部会根据isYellowColor选择颜色
        } else {
            // 当只有本设备在阅读时，使用固定颜色
            if (isYellowColor) {
                setLEDColor(255, 255, 0);  // 黄色
            } else {
                setLEDColor(255, 102, 178);  // 粉色
            }
        }
    } else {
        // 书关闭时，关闭LED
        setLEDColor(0, 0, 0);
    }
}

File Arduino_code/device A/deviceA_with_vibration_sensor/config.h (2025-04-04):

#ifndef CONFIG_H
#define CONFIG_H

#include <ESP32Servo.h>
#include <Adafruit_NeoPixel.h>
#include <WiFi.h>
#include <PubSubClient.h>
#include "arduino_secrets.h"

// 引脚定义
const int SERVO_PIN_1 = 15;       // 舵机1连接的GPIO 
const int SERVO_PIN_2 = 2;        // 舵机2连接的GPIO
const int BUTTON_PIN = 13;        // 按钮连接的GPIO
#define LED_PIN 23                // 状态指示灯引脚1
#define LED_PIN2 22               // 状态指示灯引脚2（额外照明）
#define NUM_LEDS 8                // 每个状态指示灯的LED数量
#define TIME_LED_PIN 25           // 设备A时间指示灯引脚
#define NUM_TIME_LEDS 8          // 设备A时间指示灯LED数量
#define DEVICEB_TIME_LED_PIN 26   // 设备B时间指示灯引脚
#define NUM_DEVICEB_TIME_LEDS 8 // 设备B时间指示灯LED数量
#define SW420_PIN 34
const char* MQTT_TOPIC_ISREADING_A = "student/ucfnwy2/DeviceA/isReading";          // 改为DeviceB
const char* MQTT_TOPIC_TOTALDAILYTIME_A = "student/ucfnwy2/DeviceA/totalDailyTime"; // 改为DeviceB

const char* MQTT_TOPIC_ISREADING_B = "student/ucfnwy2/DeviceB/isReading";          // 交换为DeviceA
const char* MQTT_TOPIC_TOTALDAILYTIME_B = "student/ucfnwy2/DeviceB/totalDailyTime"; // 交换为DeviceA

const char* MQTT_TOPIC_ISTOUCH = "student/ucfnwy2/isTouch";
extern bool isYellowColor;      // 当前灯光是否为黄色（false=粉色）

// 时间常量
const unsigned long UPDATE_INTERVAL = 10000;       // MQTT更新间隔（10秒）
const unsigned long BREATH_INTERVAL = 20;          // 呼吸灯更新间隔（毫秒）
const unsigned long DEBOUNCE_DELAY = 50;           // 按钮去抖动延迟（毫秒）
const unsigned long LONG_PRESS_TIME = 3000;        // 长按定义时间（3秒）
const unsigned long POMODORO_TOTAL_TIME = 3600000; // 番茄钟总时间（1小时）
const unsigned long DAY_IN_MS = 86400000;          // 一天的毫秒数
const unsigned long VIBRATION_COOLDOWN = 3000;     // 振动检测冷却时间（毫秒）
// 全局对象声明（在主文件中实例化）
extern Servo servo1;
extern Servo servo2;
extern Adafruit_NeoPixel strip;     // 第一个LED灯带（引脚23）
extern Adafruit_NeoPixel strip2;    // 第二个LED灯带（引脚22）
extern Adafruit_NeoPixel timeStrip;
extern Adafruit_NeoPixel deviceBTimeStrip;
extern WiFiClient espClient;
extern PubSubClient client;

// 全局状态变量声明（在主文件中实例化）
extern bool isOpen;                         // 书的状态
extern bool progressLEDsEnabled;            // 进度灯状态
extern unsigned long dailyReadingTime;      // 每日阅读时间
extern unsigned long startTime;             // 当前阅读会话开始时间
extern bool deviceBIsReading;               // 设备B的阅读状态
extern unsigned long deviceBTotalDailyTime; // 设备B的每日总阅读时间
extern bool isTouch;                // 当前设备的触摸状态
extern bool otherDeviceIsTouch;     // 另一台设备的触摸状态
#endif // CONFIG_H

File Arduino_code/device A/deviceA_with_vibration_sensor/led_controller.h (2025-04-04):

#ifndef LED_CONTROLLER_H
#define LED_CONTROLLER_H

#include "config.h"

// 呼吸灯相关变量
int brightness = 0;                      // 当前亮度（0-255）
bool increasing = true;                  // 亮度是否在增加
unsigned long lastBreathTime = 0;        // 上次呼吸灯更新时间

// 设置所有主LED灯带的颜色
void setLEDColor(uint8_t r, uint8_t g, uint8_t b) {
    // 设置第一个灯带（引脚23）
    for (int i = 0; i < NUM_LEDS; i++) {
        strip.setPixelColor(i, strip.Color(r, g, b));
    }
    strip.show();
    
    // 设置第二个灯带（引脚22），保持与第一个灯带同步
    for (int i = 0; i < NUM_LEDS; i++) {
        strip2.setPixelColor(i, strip2.Color(r, g, b));
    }
    strip2.show();
}

// 设置LED灯带颜色并调整亮度
void setStripColorWithBrightness(uint8_t red, uint8_t green, uint8_t blue, uint8_t brightness) {
    uint8_t r = (red * brightness) / 255;
    uint8_t g = (green * brightness) / 255;
    uint8_t b = (blue * brightness) / 255;
    
    // 设置第一个灯带（引脚23）
    for (int i = 0; i < strip.numPixels(); i++) {
        strip.setPixelColor(i, strip.Color(r, g, b));
    }
    strip.show();
    
    // 设置第二个灯带（引脚22）保持同步
    for (int i = 0; i < strip2.numPixels(); i++) {
        strip2.setPixelColor(i, strip2.Color(r, g, b));
    }
    strip2.show();
}

// 初始化所有LED灯带
void setupLEDs() {
    // 初始化主照明灯带1（引脚23）
    strip.begin();
    strip.show();
    strip.setBrightness(50);
    
    // 初始化主照明灯带2（引脚22）
    strip2.begin();
    strip2.show();
    strip2.setBrightness(50);

    // 初始化时间指示灯带
    timeStrip.begin();
    timeStrip.show();
    timeStrip.setBrightness(50);

    // 初始化设备B时间指示灯带
    deviceBTimeStrip.begin();
    deviceBTimeStrip.show();
    deviceBTimeStrip.setBrightness(50);
    
    // 初始化时，确保所有灯都是关闭状态
    setLEDColor(0, 0, 0);
    timeStrip.clear();
    timeStrip.show();
    deviceBTimeStrip.clear();
    deviceBTimeStrip.show();
    
    Serial.println("所有LED灯带已初始化并设置为关闭状态");
}

// 修改呼吸灯效果函数以支持不同颜色
void updateBreathingEffect() {
    unsigned long currentTime = millis();
    if (currentTime - lastBreathTime >= BREATH_INTERVAL) {
        if (increasing) {
            brightness += 5;
            if (brightness >= 255) {
                brightness = 255;
                increasing = false;
            }
        } else {
            brightness -= 5;
            if (brightness <= 0) {
                brightness = 0;
                increasing = true;
            }
        }
        
        // 根据当前颜色状态选择不同的RGB值
        if (isYellowColor) {
            // 黄色呼吸灯
            setStripColorWithBrightness(255, 255, 0, brightness);
        } else {
            // 粉色呼吸灯
            setStripColorWithBrightness(255, 102, 178, brightness);
        }
        
        lastBreathTime = currentTime;
    }
}

// 兼容原有代码的呼吸灯函数重载
void updateBreathingEffect(uint8_t red, uint8_t green, uint8_t blue) {
    // 调用无参数版本，颜色已在其中处理
    updateBreathingEffect();
}

// 更新设备A时间指示灯
void updateTimeLEDs() {
    // 如果进度灯被禁用，直接返回
    if (!progressLEDsEnabled) {
        return;
    }
    
    // 如果设备A未阅读（且不是当前在阅读），则关闭进度灯
    if (dailyReadingTime == 0 && !isOpen) {
        timeStrip.clear();
        timeStrip.show();
        return;
    }
    
    unsigned long totalTime = dailyReadingTime;
    if (isOpen && startTime > 0) {
        totalTime += (millis() - startTime);
    }
    unsigned long totalSeconds = totalTime / 1000;

    // 正常亮灯逻辑
    int ledsToLight = 0;
    if (totalSeconds < 450) {
        ledsToLight = 1;
    } else if (totalSeconds < 900) {
        ledsToLight = 2;
    } else if (totalSeconds < 1350) {
        ledsToLight = 3;
    } else if (totalSeconds < 1800) {
        ledsToLight = 4;
    } else if (totalSeconds < 2250) {
        ledsToLight = 5;
    } else if (totalSeconds < 2700) {
        ledsToLight = 6;
    } else if (totalSeconds < 3150) {
        ledsToLight = 7;
    } else {
        ledsToLight = 8;
    }

    for (int i = 0; i < NUM_TIME_LEDS; i++) {
        if (i < ledsToLight) {
            timeStrip.setPixelColor(i, timeStrip.Color(255, 102, 178));  // 粉色
        } else {
            timeStrip.setPixelColor(i, timeStrip.Color(0, 0, 0));    // 关闭
        }
    }
    timeStrip.show();
}

// 更新设备B时间指示灯
void updateDeviceBTimeLEDs() {
    // 如果进度灯被禁用，直接返回
    if (!progressLEDsEnabled) {
        return;
    }
    
    // 如果设备B未阅读，则关闭进度灯
    if (deviceBTotalDailyTime == 0 && !deviceBIsReading) {
        deviceBTimeStrip.clear();
        deviceBTimeStrip.show();
        return;
    }
    
    unsigned long totalSeconds = deviceBTotalDailyTime;

    // 正常亮灯逻辑
    int ledsToLight = 0;
    if (totalSeconds < 450) {
        ledsToLight = 1;
    } else if (totalSeconds < 900) {
        ledsToLight = 2;
    } else if (totalSeconds < 1350) {
        ledsToLight = 3;
    } else if (totalSeconds < 1800) {
        ledsToLight = 4;
    } else if (totalSeconds < 2250) {
        ledsToLight = 5;
    } else if (totalSeconds < 2700) {
        ledsToLight = 6;
    } else if (totalSeconds < 3150) {
        ledsToLight = 7;
    } else {
        ledsToLight = 8;
    }
    
    for (int i = 0; i < NUM_DEVICEB_TIME_LEDS; i++) {
        if (i < ledsToLight) {
            deviceBTimeStrip.setPixelColor(i, deviceBTimeStrip.Color(102, 178, 255));  // 蓝色
        } else {
            deviceBTimeStrip.setPixelColor(i, deviceBTimeStrip.Color(0, 0, 0));    // 关闭
        }
    }
    deviceBTimeStrip.show();
}

// 切换进度条LED灯的状态
void toggleLEDs() {
    progressLEDsEnabled = !progressLEDsEnabled;
    
    if (!progressLEDsEnabled) {
        // 关闭两个进度条LED灯
        timeStrip.clear();
        timeStrip.show();
        
        deviceBTimeStrip.clear();
        deviceBTimeStrip.show();
        
        Serial.println("进度条LED灯带(D25, D26)：关闭");
    } else {
        // 重新启用进度条LED灯（会在下一次更新循环中根据阅读时间自动点亮）
        Serial.println("进度条LED灯带(D25, D26)：启用");
        // 立即更新一次灯带状态
        updateTimeLEDs();
        updateDeviceBTimeLEDs();
    }
}

#endif // LED_CONTROLLER_H

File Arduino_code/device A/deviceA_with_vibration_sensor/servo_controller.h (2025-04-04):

#ifndef SERVO_CONTROLLER_H
#define SERVO_CONTROLLER_H

#include "config.h"

// 添加舵机当前角度的全局变量
int currentServo1Angle = 0;  // 舵机1当前角度
int currentServo2Angle = 180;  // 舵机2当前角度

// 初始化舵机
void setupServos() {
    servo1.attach(SERVO_PIN_1);
    servo2.attach(SERVO_PIN_2);
    
    // 初始化舵机位置（闭合状态）
    servo1.write(0);
    servo2.write(180);
    currentServo1Angle = 0;
    currentServo2Angle = 180;
}

// 设置两个舵机的角度
void setServoAngles(int angle1, int angle2) {
    servo1.write(angle1);
    servo2.write(angle2);
    // 更新当前角度
    currentServo1Angle = angle1;
    currentServo2Angle = angle2;
}

// 渐进式移动舵机的函数
void moveServos(int startAngle, int endAngle, int step, int delayTime) {
    if (step > 0) {
        for (int angle = startAngle; angle <= endAngle; angle += step) {
            int reversedAngle = 180 - angle;
            setServoAngles(angle, reversedAngle);
            delay(delayTime);
        }
    } else {
        for (int angle = startAngle; angle >= endAngle; angle += step) {
            int reversedAngle = 180 - angle;
            setServoAngles(angle, reversedAngle);
            delay(delayTime);
        }
    }
}

// 打开书（将舵机渐进移动到打开位置）
void openBook() {
    Serial.println("Opening the book...");
    // 从当前位置到180度
    moveServos(currentServo1Angle, 180, 5, 100);
    Serial.println("Book is open!");
}

// 关闭书（将舵机从当前位置渐进移动到闭合位置）
void closeBook() {
    Serial.println("Closing the book...");
    // 从当前位置到0度
    moveServos(currentServo1Angle, 0, -5, 100);
    Serial.println("Book is closed!");
}

#endif // SERVO_CONTROLLER_H

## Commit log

2025-03-23 Fix timer bug in shifting page
2025-04-05 Update Reademe_Frame
    [Enclosure_split.3dm, finalholder.stl]
2025-04-06 Update Readme Frame
2025-04-13 Rename PCB.png to Circuit diagram.png
